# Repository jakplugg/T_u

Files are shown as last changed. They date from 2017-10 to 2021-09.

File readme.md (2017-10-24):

# T_&#956; 

### 8hp version of Temps utile 6x clock generator by MXMXMX.

#### PCB redesign by J. Matheson. it works with the same firmware.

[Temps_utile project and manual, etc](https://github.com/mxmxmx/temps_utile-/wiki/Temps-Utile)

[Google sheets BOM](https://docs.google.com/spreadsheets/d/1YzoKF_4KADmYcHr4SySU5rFkUqZim7LaVXBFByAKBcs/edit?usp=sharing "BOM")

Note about the panel: there are 2 different hole spacing for the displays, Adafruit or ones made from the adafruit gerbers will fit the FPD panel in the panel folder. chinese ones from ebay, amazon, alliexpress, etc have a different hole spacing (see the pdf for oval holes used on PCB-panel) the PCB also has oval holes to support both displays.

There are Gerber files for a budget "pcb panel" in the gerbers folder.

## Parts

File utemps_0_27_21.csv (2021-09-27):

RefDes | Name | Pattern | Origin X (in) | Origin Y (in) | Side | Rotate | Value
C1 | CPOL-USC | CAPAE-5.3x5.3h3 | 1.1732 | 2.7642 | Top | 90.0 | 22u
C2 | CPOL-USC | CAPAE-5.3x5.3h3 | 0.7607 | 2.6142 | Top | 270.0 | 22u
C3 | CAP_0603 | CAP_0805 | 0.4983 | 1.9628 | Top | 180.0 | 1n
C4 | CAP_0603 | CAP_0805 | 1.1233 | 2.0003 | Top | 180.0 | 18n
C5 | CAP_0603 | CAP_0805 | 1.2982 | 2.2378 | Top | 180.0 | 1n
C6 | CAP_0805 | CAP_0805 | 1.5607 | 0.9814 | Top | 0.0 | 0.1u
C7 | CPOL-USC | CAPAE-4.3x4.3h5.4 | 1.7045 | 3.9316 | Top | 90.0 | 10u
C8 | CAP_0805 | CAP_0805 | 1.6046 | 2.5315 | Top | 180.0 | 0.1u
C9 | CAP_0805 | CAP_0805 | 1.5919 | 0.4628 | Top | 0.0 | 0.1u
C10 | CAP_0805 | CAP_0805 | 0.9857 | 2.2064 | Top | 90.0 | 0.1u
C11 | CAP_0805 | CAP_0805 | 0.8107 | 0.9878 | Top | 0.0 | 0.1u
C12 | CAP_0805 | CAP_0805 | 0.8544 | 1.3253 | Top | 0.0 | 0.1u
C13 | CAP_0805 | CAP_0805 | 0.8545 | 0.7689 | Top | 0.0 | 0.1u
C14 | CAP_0805 | CAP_0805 | 1.6545 | 2.9376 | Top | 0.0 | 0.47u
C15 | CAP_0805 | CAP_0805 | 0.7482 | 0.4502 | Top | 0.0 | 0.1u
C16 | CAP_0805 | CAP_0805 | 0.842 | 1.8064 | Top | 0.0 | 0.1u
C17 | CAP_0805 | CAP_0805 | 0.7482 | 1.4377 | Top | 0.0 | 0.1u
C18 | CAP_0603 | CAP_0805 | 0.6858 | 2.394 | Top | 0.0 | 3.3n
C22 | CAP_0805 | CAP_0805 | 0.7294 | 1.9003 | Top | 180.0 | 0.1u
C23 | CAP_0805 | CAP_0805 | 1.8607 | 1.6002 | Top | 90.0 | 1u
C24 | CPOL-USC | CAPAE-4.3x4.3h5.4 | 1.0859 | 4.044 | Top | 0.0 | 10u
C28 | CAP_0805 | CAP_0805 | 1.2483 | 1.769 | Top | 90.0 | 1u
C29 | CAP_0805 | CAP_0805 | 1.4671 | 2.9128 | Top | 180.0 | 0.47u
C30 | CAP_0805 | CAP_0805 | 1.5357 | 3.8439 | Top | 90.0 | 0.1u
C31 | CAP_0805 | CAP_0805 | 0.817 | 3.8377 | Top | 90.0 | 0.1u
C32 | CAP_0805 | CAP_0805 | 1.592 | 4.5249 | Top | 270.0 | 0.1u
C33 | CAP_0805 | CAP_0805 | 0.5296 | 2.9065 | Top | 180.0 | 0.47u
CL1 | Thonkiconn | Thonkiconn Jack | 0.9795 | 1.657 | Bottom | 180.0
CL2 | Thonkiconn | Thonkiconn Jack | 0.6045 | 1.657 | Bottom | 180.0
CL3 | Thonkiconn | Thonkiconn Jack | 0.9795 | 1.1503 | Bottom | 180.0
CL4 | Thonkiconn | Thonkiconn Jack | 0.6045 | 1.1503 | Bottom | 180.0
CL5 | Thonkiconn | Thonkiconn Jack | 0.9795 | 0.644 | Bottom | 180.0
CL6 | Thonkiconn | Thonkiconn Jack | 0.6045 | 0.644 | Bottom | 180.0
D7 | MB1S | SOP-4/6.5x2.54 | 1.6295 | 4.2561 | Top | 180.0 | MB1S
E1 | PEC11 | PEC11 | 1.567 | 2.544 | Bottom | 180.0
E2 | PEC11 | PEC11 | 0.767 | 2.544 | Bottom | 180.0
IC6 | REG1117T | TO252 | 0.6023 | 4.0926 | Top | 180.0 | LM1117-5
J2 | JUMPER_3 | JMP3 | 0.792 | 0.869 | Top | 0.0
J5 | Thonkiconn | Thonkiconn Jack | 1.7295 | 1.6565 | Bottom | 180.0
J6 | Thonkiconn | Thonkiconn Jack | 1.3545 | 1.6565 | Bottom | 180.0
J9 | Thonkiconn | Thonkiconn Jack | 1.7295 | 1.1503 | Bottom | 180.0
J10 | Thonkiconn | Thonkiconn Jack | 1.3545 | 1.1503 | Bottom | 180.0
J11 | Thonkiconn | Thonkiconn Jack | 1.7295 | 0.644 | Bottom | 180.0
J12 | Thonkiconn | Thonkiconn Jack | 1.3545 | 0.644 | Bottom | 180.0
JP1 | M05X2PTH | AVR_ICSP | 1.1733 | 4.394 | Top | 270.0 | M05X2PTH
Q1 | MMBT3904 | SOT23 | 1.4857 | 2.658 | Top | 90.0
Q2 | MMBT3904 | SOT23 | 1.4858 | 2.3737 | Top | 270.0
R1 | RES_0805 | RES_0805 | 1.0857 | 1.7315 | Top | 180.0 | 10k
R2 | RES_0805 | RES_0805 | 0.4982 | 1.7315 | Top | 0.0 | 10k
R3 | RES_0805 | RES_0805 | 1.0857 | 1.6315 | Top | 0.0 | 20k
R4 | RES_0805 | RES_0805 | 1.0919 | 1.5253 | Top | 180.0 | 1k
R5 | RES_0805 | RES_0805 | 0.4921 | 1.6315 | Top | 180.0 | 20k
R6 | RES_0805 | RES_0805 | 0.4919 | 1.5253 | Top | 0.0 | 1k
R7 | RES_0805 | RES_0805 | 1.1046 | 1.319 | Top | 180.0 | 10k
R8 | RES_0805 | RES_0805 | 1.1044 | 1.2065 | Top | 0.0 | 20k
R9 | RES_0805 | RES_0805 | 1.1044 | 1.094 | Top | 180.0 | 1k
R10 | RES_0805 | RES_0805 | 0.4921 | 1.2253 | Top | 0.0 | 10k
R11 | RES_0805 | RES_0805 | 0.4919 | 1.119 | Top | 180.0 | 20k
R12 | RES_0805 | RES_0805 | 0.4921 | 1.019 | Top | 180.0 | 1k
R15 | RES_0805 | RES_0805 | 1.6169 | 1.744 | Top | 90.0 | 100k
R16 | RES_0805 | RES_0805 | 1.617 | 1.9252 | Top | 270.0 | 33k
R17 | RES_0805 | RES_0805 | 1.4794 | 1.7503 | Top | 90.0 | 100k
R18 | RES_0805 | RES_0805 | 1.4857 | 1.9252 | Top | 270.0 | 33k
R19 | RES_0805 | RES_0805 | 1.6482 | 2.6753 | Top | 270.0 | 47k
R20 | RES_0805 | RES_0805 | 1.6482 | 2.3816 | Top | 90.0 | 47k
R21 | RES_0805 | RES_0805 | 1.1046 | 0.7878 | Top | 180.0 | 10k
R22 | RES_0805 | RES_0805 | 1.1046 | 0.669 | Top | 0.0 | 20k
R23 | RES_0805 | RES_0805 | 1.8545 | 0.9064 | Top | 90.0 | 100k
R24 | RES_0805 | RES_0805 | 1.8357 | 1.044 | Top | 180.0 | 33k
R25 | RES_0805 | RES_0805 | 1.842 | 1.1689 | Top | 0.0 | 100
R26 | RES_0805 | RES_0805 | 1.8607 | 1.4191 | Top | 270.0 | 75k
R27 | RES_0805 | RES_0805 | 1.467 | 0.8377 | Top | 90.0 | 100k
R28 | RES_0805 | RES_0805 | 1.3357 | 1.0627 | Top | 0.0 | 33k
R29 | RES_0805 | RES_0805 | 1.3357 | 1.1752 | Top | 180.0 | 100
R30 | RES_0805 | RES_0805 | 1.4795 | 1.4128 | Top | 270.0 | 75k
R31 | RES_0805 | RES_0805 | 1.8357 | 0.5128 | Top | 0.0 | 100k
R32 | RES_0805 | RES_0805 | 1.8546 | 0.619 | Top | 180.0 | 33k
R33 | RES_0805 | RES_0805 | 1.8544 | 0.7315 | Top | 0.0 | 100
R34 | RES_0805 | RES_0805 | 1.6107 | 1.4128 | Top | 270.0 | 75k
R35 | RES_0805 | RES_0805 | 1.2171 | 0.4565 | Top | 180.0 | 100k
R36 | RES_0805 | RES_0805 | 1.3545 | 0.5752 | Top | 0.0 | 33k
R37 | RES_0805 | RES_0805 | 1.3545 | 0.6814 | Top | 180.0 | 100
R38 | RES_0805 | RES_0805 | 1.2545 | 1.4128 | Top | 270.0 | 75k
R39 | RES_0805 | RES_0805 | 1.2545 | 1.5941 | Top | 270.0 | 2k
R40 | RES_0805 | RES_0805 | 1.4232 | 3.8439 | Top | 90.0 | 510
R41 | RES_0805 | RES_0805 | 0.942 | 3.8377 | Top | 90.0 | 510
R42 | RES_0805 | RES_0805 | 0.7482 | 4.5939 | Top | 90.0 | 10k
R43 | RES_0805 | RES_0805 | 1.1045 | 0.5564 | Top | 180.0 | 1k
R44 | RES_0805 | RES_0805 | 0.4857 | 0.7315 | Top | 0.0 | 10k
R45 | RES_0805 | RES_0805 | 0.4857 | 0.6253 | Top | 180.0 | 20k
R46 | RES_0805 | RES_0805 | 0.4919 | 0.5253 | Top | 0.0 | 1k
R47 | RES_0603 | RES_0805 | 0.5171 | 2.394 | Top | 0.0 | 3k9
R48 | RES_0603 | RES_0805 | 0.5171 | 2.2878 | Top | 180.0 | 3k
R49 | RES_0603 | RES_0805 | 0.5171 | 2.1815 | Top | 180.0 | 6k8
R50 | RES_0603 | RES_0805 | 0.5169 | 2.069 | Top | 0.0 | 1k8
R51 | RES_0603 | RES_0805 | 1.117 | 2.1189 | Top | 180.0 | 1k2
R52 | RES_0603 | RES_0805 | 1.1171 | 2.2565 | Top | 180.0 | 3k
R53 | RES_0603 | RES_0805 | 1.8044 | 2.7687 | Top | 0.0 | 100k
R54 | RES_0603 | RES_0805 | 1.2982 | 2.1128 | Top | 0.0 | 4k2
R60 | R-US_R1206 | R1206 | 1.361 | 4.044 | Top | 180.0 | 4.7
U1 | Teensy 3.2_temps | Teensy3.2_temps_utile | 1.217 | 3.344 | Top | 270.0
U2 | TL072BID | SOIC-8/150mil | 0.792 | 1.6315 | Top | 180.0
U3 | TL072BID | SOIC-8/150mil | 0.792 | 1.1503 | Top | 180.0
U4 | MIC803 supervisor | SOT23 | 1.8029 | 2.8999 | Top | 180.0 | MIC803
U5 | MCP6002 | SOIC-8/150mil | 1.5857 | 1.144 | Top | 180.0
U6 | LM4040_EM3-5.0 | SOT23 | 1.5373 | 1.5753 | Top | 270.0
U7 | TL072BID | SOIC-8/150mil | 0.792 | 0.6128 | Top | 180.0
U8 | 6mm Tactile SW | TL1105SP | 1.567 | 3.2296 | Bottom | 90.0
U9 | 6mm Tactile SW | TL1105SP | 0.767 | 3.2296 | Bottom | 270.0
U10 | MCP6002 | SOIC-8/150mil | 1.592 | 0.619 | Top | 180.0
U11 | 1306_disp_O_C | 1306_disp_O_C | 1.167 | 4.4936 | Bottom | 180.0
U12 | TL072ACD | SOIC-8/150mil | 0.792 | 2.0565 | Top | 0.0
U13 | ADP150 3.3V | SOT23-5 | 1.8171 | 2.1721 | Top | 270.0 | ADP150 3.3V

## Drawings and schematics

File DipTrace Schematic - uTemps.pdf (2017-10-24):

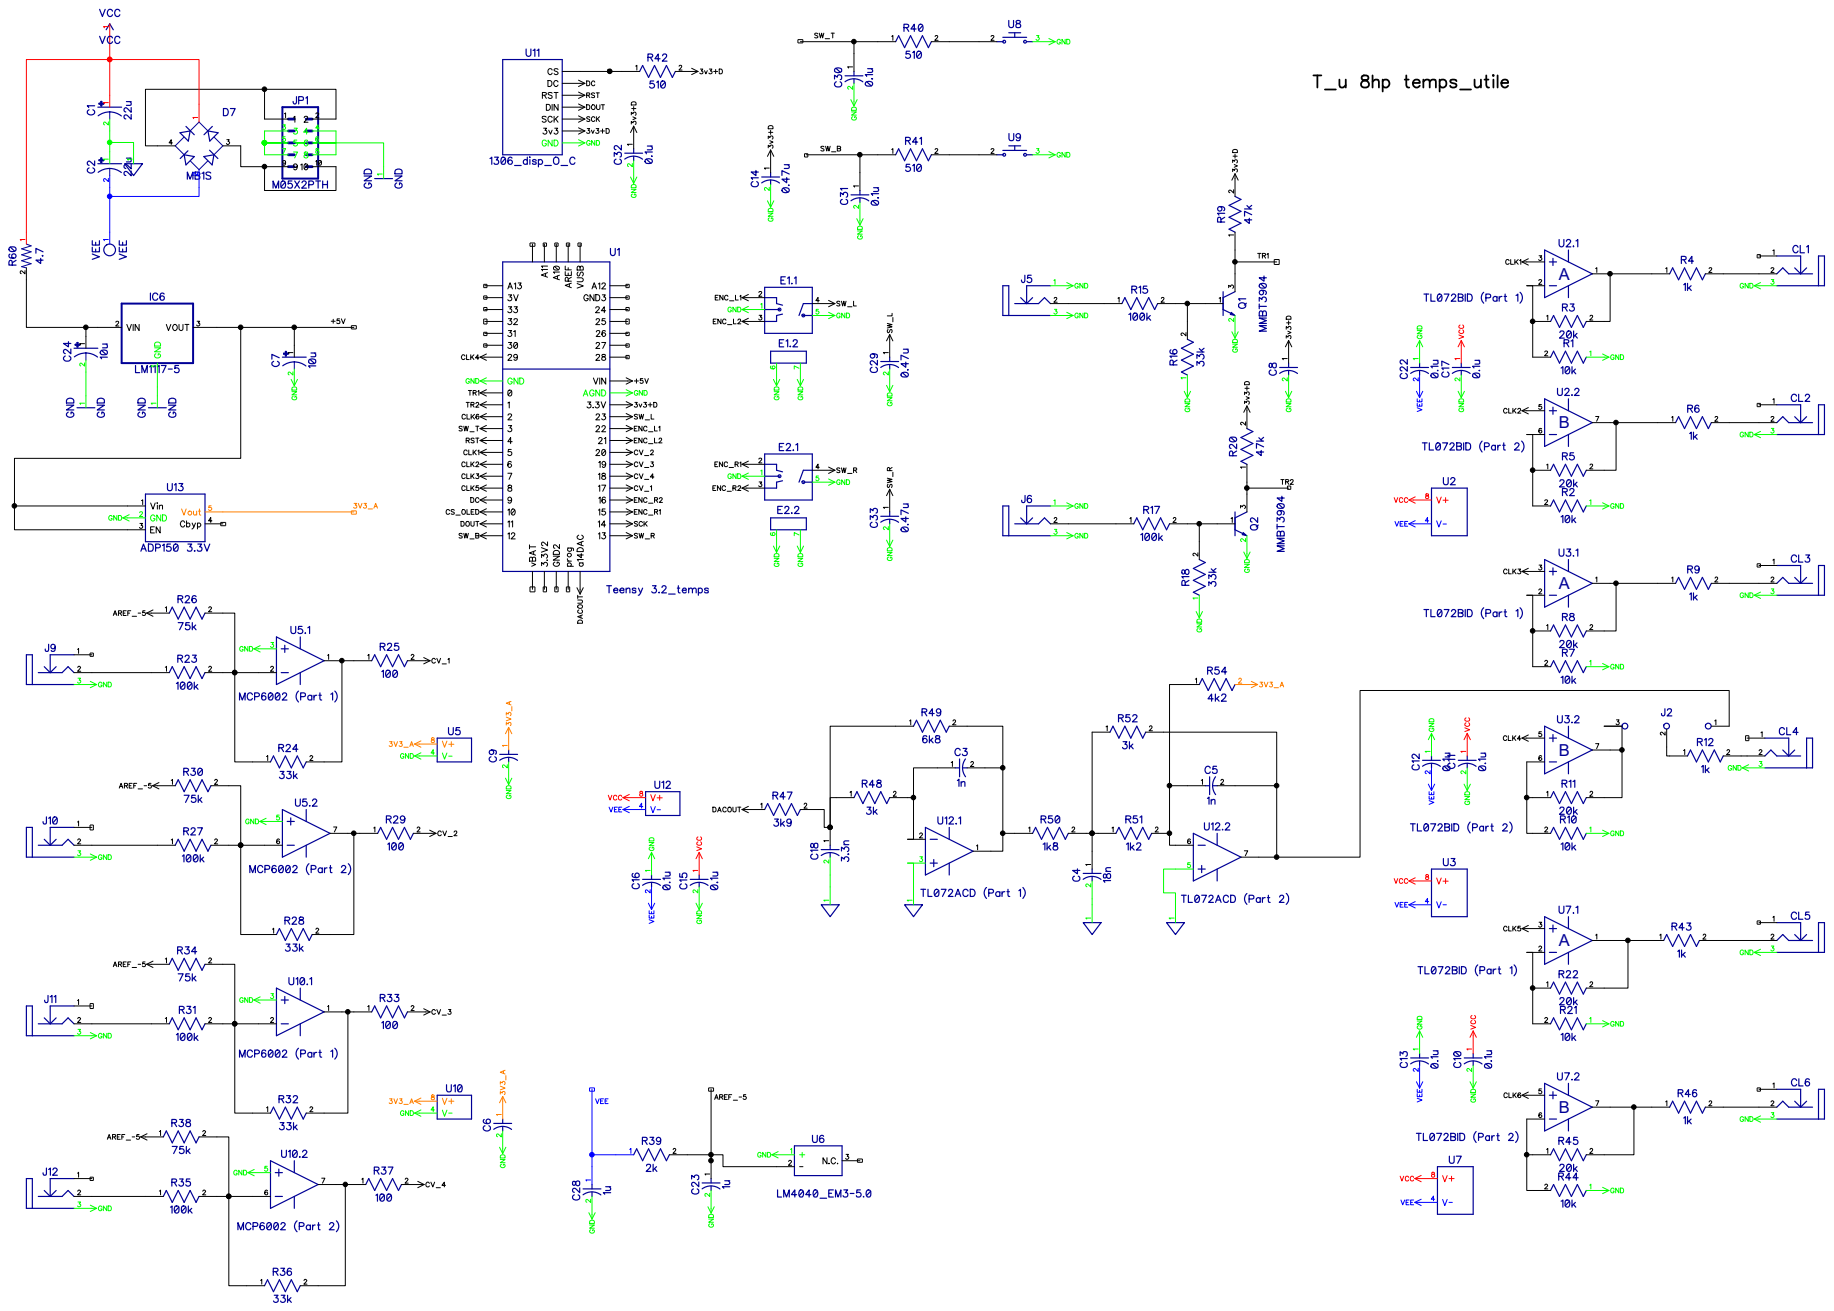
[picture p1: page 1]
ABABAB

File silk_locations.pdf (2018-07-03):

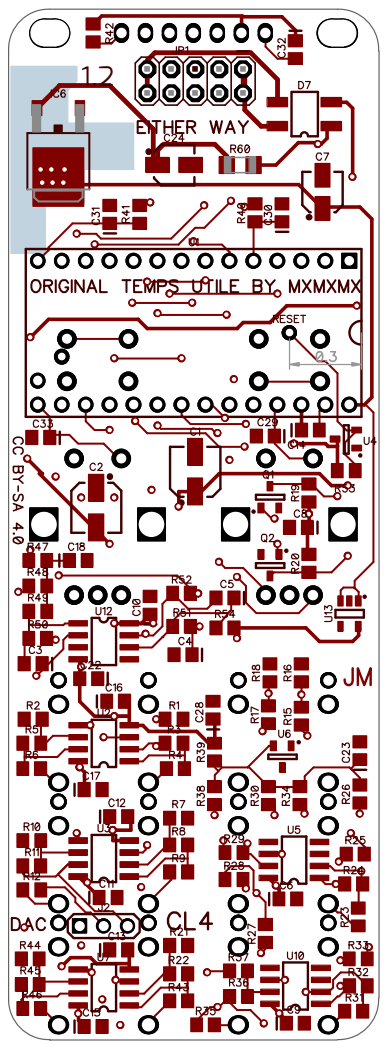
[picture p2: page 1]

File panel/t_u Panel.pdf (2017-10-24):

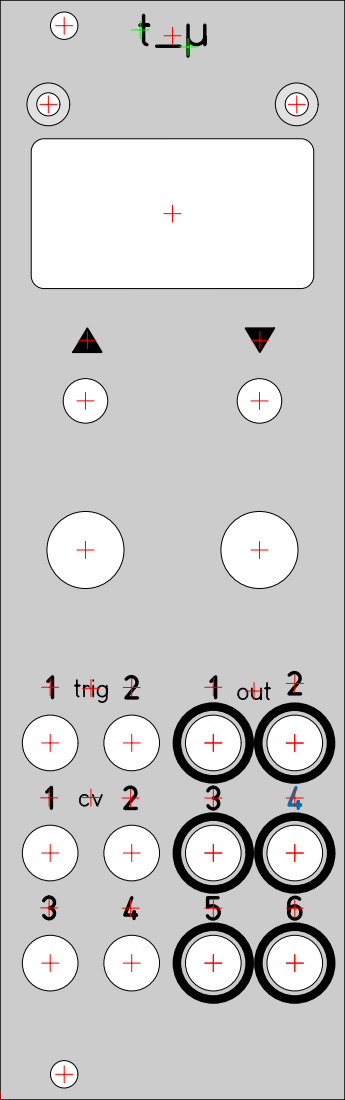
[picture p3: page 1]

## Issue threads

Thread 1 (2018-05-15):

rev 1.1 MIC803 / Pogo pin fix

tdball, 2018-05-15:
Didn't see any documentation on resolving the rev1.1 board's issues with unstable voltage on power up not actually allowing the module to come up with the rest of the rack.
Any pointers as to resolving this?

jakplugg, 2018-05-15:
We have not written anything up for it yet, ill try and get something
posted by the weekend. basically:

It has a spot for an optional MIC803 supervisor chip and associated
100k resistor, but you have to source a pogo pin that matches the
height of the headers you used for the teensy, it touches the reset
pad on the bottom of the teensy.

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

Rackbrute, 2023-02-07:
Hi. Did this get resolved? I have a uTU from After Later and it has power-up issues. Takes about 4 rack power cycles before it will power on and boot up.

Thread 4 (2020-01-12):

BOM Mouser part incorrect

forrestbaer, 2020-01-12:
The current BOM shows "579-MCP6004T-I/SL" for the 2x op-amps needed, that's the part number for the SOIC-14 version, while the board needs the SOIC-8 package "579-MCP6002T-I/SN"

jakplugg, 2020-01-12:
Sorry, i only own the google sheets BOM, not any of the mouser ones,
it seems to be already correct?

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

forrestbaer, 2020-01-12:
That is from the google sheets BOM, that mouser part listed in the google sheets bom:  "579-MCP6004T-I/SL" (SOIC-14, 7 pin) I believe should be "579-MCP6002T-I/SN" (SOIC-8, 4 pin)

grantHarris, 2020-03-25:
Ugh. This burned me. Ended up ordering the MCP6004T part without noticing.

jakplugg, 2020-03-25:
I checked the BOM sheet and the link on the repo and they both seem
right, is there an old BOM floating about? maybe it should be deleted.

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

grantHarris, 2020-03-25:
https://docs.google.com/spreadsheets/d/1YzoKF_4KADmYcHr4SySU5rFkUqZim7LaVXBFByAKBcs/edit#gid=1626775796

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

jakplugg, 2020-03-25:
Sorry It was me looking at the wrong one, fixed!

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

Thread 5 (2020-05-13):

Missing drill file?

terje, 2020-05-13:
Heya,

Thanks for your effort on this! It's great to have Temps Utile available in 8HP :)

I think the circuit board gerber file is missing the drill file, however. Could you add it in?

Thanks!

Kindly, Terje

jakplugg, 2020-05-14:
the "NC" file is the drill file, you could rename the file extension to "DRL"

terje, 2020-05-15:
Thanks so much, I didn't know that!

Closed 2020-05-17.

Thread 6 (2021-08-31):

Why is R51 specified as 0603?

bengarland, 2021-08-31:
Why is R51 specified as 0603? The pad is 0805 like all the others on the board.

jakplugg, 2021-12-19:
just a mistake, sorry! use either one, you can fit 0603 on 0805 with manual soldering.

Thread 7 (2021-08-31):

BOM and PNP don't match for some resistor values

bengarland, 2021-08-31:
BOM says R26, R30, R34, and R38 are 100k

PNP says they're 75k

Which is correct?

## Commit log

2018-03-15 updated gerbers
    there were no mounting holes for the display!
2018-04-07 1.21 gerber
    cleaned up heatsink area solder mask
2021-04-24 added pnp
    [uTemps12_PNP.csv]
2021-09-27 opdated gerbs
    [uTemp1.2.DRL, uTemp1.2.GBL, uTemp1.2.GBO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]
